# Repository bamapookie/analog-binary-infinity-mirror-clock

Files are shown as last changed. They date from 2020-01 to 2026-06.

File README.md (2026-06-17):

# Analog Binary Infinity Mirror Clock

Plans, parts, and code for building your very own clock that no one can read. (Except you... maybe.)

> **Status:** Resurrecting an abandoned build. The firmware targets an Adafruit
> ItsyBitsy M4 (SAMD51) driving six APA102/DotStar rings, disciplined by a GPS
> module so it never needs to be set. See [`ROADMAP.md`](ROADMAP.md) for what's
> planned next (library extraction, a desk-sized revision, and magnet-based
> configuration). Project boards on [CADLAB.io](https://cadlab.io/project/2407).

## The Concept

Everyone knows analog clocks--2 or 3 hands moving around a clock face, indicating hours, minutes, and sometimes
seconds. It is easy to get a sense of time progressing by watching the hands move around, or gauging the position of one
hand in relation to the numbers (or even just the angles) to fill in an appropriate sense of precision.

Most people have seen binary clocks--Several obscure lights flickering on and off in a seemingly random pattern with
no markings to indicate number groupings, then having to decode the lights into a usable number. Some people cheat and
use Binary Coded Decimal in order to only have to decode one digit at a time.

What the world really needs is a way to combine the obscurity and complexity of decoding a binary number into a usable
format with the intrinsic sense of progress you get from the movement of the hands of an analog clock.

Thus began my quest to build a Binary Analog Clock! 11 hands moving around a clock face with only a '0' and a '1' to
adorn it. Now how the #^%\$% am I going to build a clock with 11 hands? I searched Google. Couldn't find anything
remotely resembling a kit for building an 11 handed clock. (IKR?) So I sat on it for a while, then I saw an infinity
mirror with NeoPixels in it, and it clicked. The infinity mirror effect could look like a line, and radiating in from
pixels on the outer ring, it could look like a hand. I finally had my plan. I dropped a boatload of money on Adafruit
and my local MicroCenter (See the materials list below, and thanks LadyAda for having such a fantastic operation.) and
started to work.

## The Plan

#### Basic plan

Basically, an infinity mirror is made with two mirrors facing each other. The mirror closest to you is semi-transparent.
This allows some of the light through, but the rest of the light bounces back and repeats the process. This makes the
space between the mirrors appear to extend beyond the back mirror. Between the mirrors, we will place 6 concentric
circles of DotStar pixels facing inward. Each of these will be a "hand" representing one bit of the binary number.
All six rings will be used to indicate minutes (2^6 = 64 > 60). The five innermost circles will also indicate hours
(2^5 = 32 > 24), using a slightly wider hand to distinguish it from the minute hands. I also have a plan for indicating
seconds by having the seconds "ripple" out from the corresponding minute hands, making the clock even more unreadable.

#### Intermediate plan

We want the "mechanics" to be small, so we'll use an Itsy Bitsy M4 to drive everything with a few other chips to bring up
the logic voltage to the DotStars. We'll print PCBs to mount it all on and stick it behind the clock.

#### Complex Plan

This is a clock. Clocks, in their default state, only blink 001100:000000 over and over again. We don't want that! We
want a clock that keeps its time. Moreover, we don't want to have to set it. Ever. Let's throw a GPS on there and we
won't ever have to set it! We'll just need to spend and extra few weeks figuring out the GPS code, how to set the time
from it, and wait... GPS time isn't the same as UTC time? UTC time has leap seconds? The standard time library
doesn't handle leap seconds or milliseconds? This won't do.

#### Overly Complex Plan

Let's rewrite the Arduino Time libraries, the GPS libraries, and the TimeZone libraries to handle leap seconds and
milliseconds. And because I laugh at my own jokes, we'll make it blink 001100:000000 for a little while when we turn
it on.

Okay. Maybe that is overdoing it. How about we keep track of the seconds separately, and just use the time libraries
for minute-level precision. We will increment the seconds using the PPS signal and data from the GPS on when leap
seconds occur, then update the GPS time when we determine a minute rollover has occured. This will also handle the
delay between the actual start of a second and the time that the NMEA message containing the time arrives from the GPS.

## The Implementation

Parts acquired... let's go!

While the final product will use an Itsy Bitsy M4 Express, I'm prototyping it with a Feather M4 Express. When I get the
IBM4, I'll use the Feather M4 Express along with an OLED display and another chip to measure the power usage of the
DotStars to make sure I have the right size power supply.

So now I have the breadboard out with one freshly soldered Feather M4 Express, one freshly soldered GPS Breakout board,
and a 1 meter length DotStar Strip.

#### Phase 1 - Testing the components

Using the default strandtest.ino from Adafruit with minor modifications, I tested out the DotStar strips. (See the
[`examples/`](examples/) folder for the strand and GPS bring-up sketches.)

PPS Test

GPS Test

#### Phase 2 - Hardware

Designing the PCB
Designing the Frame

#### Phase 3 - Writing the code

## Useful Links

##### Parts Lists

- https://www.adafruit.com/wishlists?wid=482342

##### Microcontrollers

- https://learn.adafruit.com/adafruit-feather-m4-express-atsamd51/overview
- https://learn.adafruit.com/introducing-adafruit-itsybitsy-m4/overview

##### Programming (C, C++)

- https://www.arduino.cc/reference/en/#functions
- http://www.gammon.com.au/forum/?id=11488
- https://forum.arduino.cc/index.php?topic=503368.0
- https://create.arduino.cc/projecthub/GadgetsToGrow/don-t-delay-use-an-arduino-task-scheduler-today-215cfe
- https://github.com/arkhipenko/TaskScheduler

##### DotStars

- https://learn.adafruit.com/adafruit-dotstar-leds/overview
- https://github.com/adafruit/Adafruit_DotStar
- https://wp.josh.com/2015/12/22/getting-real-using-blind-send-spi-to-turbocharge-the-adafruit-dotstar-library/

##### FastLED

- https://fastled.io/
- https://github.com/FastLED/FastLED
- https://www.reddit.com/r/FastLED/

##### GPS

- http://www.hhhh.org/wiml/proj/nmeaxor.html
- http://aprs.gids.nl/nmea/
- http://arduiniana.org/libraries/tinygpsplus/
- https://github.com/mikalhart/TinyGPSPlus
- http://www.flytron.com/pdf/MTK_commands.pdf
- https://en.wikipedia.org/wiki/NMEA_0183

###### Adafruit Ultimate GPS Breakout Board

- https://github.com/adafruit/Adafruit_GPS
- https://learn.adafruit.com/adafruit-ultimate-gps/overview
- https://forums.adafruit.com/viewtopic.php?f=19&t=148591&p=734292#p733660
- https://cdn-shop.adafruit.com/datasheets/GlobalTop-FGPMMOPA6C-Datasheet-V0A-Preliminary.pdf
- https://cdn-shop.adafruit.com/datasheets/PMTK_A11.pdf
- http://www.alphamicrowireless.com/franchises/globaltop-technology/pa6h.aspx

###### SparkFun GPS Breakout - XA1110

- https://www.sparkfun.com/products/14414
- https://www.sparkfun.com/datasheets/GPS/Modules/PMTK_Protocol.pdf

##### Components
- https://learn.sparkfun.com/tutorials/capacitors/all

##### Time

- https://www.pjrc.com/teensy/td_libs_Time.html
- https://www.davidpilling.com/wiki/index.php/GPS#a6
- https://github.com/PaulStoffregen/Time
- https://forum.arduino.cc/index.php?topic=503368.0
- https://github.com/JChristensen/Timezone

##### PCBs

- https://www.autodesk.com/products/eagle/free-download
- https://learn.adafruit.com/making-pcbs-with-oshpark-and-eagle/ordering-and-assembly
- https://oshpark.com/
- http://kicad-pcb.org/download/windows/
- https://cadlab.io ([My project](https://cadlab.io/project/2407)). 

##### Soldering

- https://www.youtube.com/watch?v=VxMV6wGS3NY

##### Random

- https://arduino.stackexchange.com/questions/348/how-to-organize-my-arduino-projects-structure-for-easy-source-control
- http://www.gammon.com.au/forum/?id=11488

## Addendum
#### Leap Seconds
During testing of the GPS is when I discovered the possible occurrence of leap seconds.  Every couple of years, or so, 
an extra second (or 2) is added to (or removed from) the last minute of June or December, UTC.  So instead of the 
seconds counting 58, 59, 60/0, 1, 2, etc., they might add an extra second (59, 60, 61/0, 1, 2), an extra 2 seconds 
(59, 60, 61, 62/0, 1, 2), or take away a second (58, 59/0, 1, 2).  All of this is to keep UTC in sync with UT1, which is 
the actual time based on the position of the earth in relation to the position of the stars.   UT1 drifts due to tidal 
forces changing the speed that the earth rotates.  Whenever the difference between UTC and UT1 reaches .9 seconds, leap 
seconds are used to correct the imbalance.

Unix clocks usually just ignore this.  They just leave the time at 23:59:59 until 00:00:00 eventually gets here.  All of
the time libraries used in Arduino environments also ignore this, and make no attempt to handle it.

## Repository Layout

- `src/` — the clock firmware (`main.cpp`).
- `lib/` — project libraries: board pin maps (`abimc_pcb`) and GPS command sets (`xa1110`, `mtk33x9`).
- `examples/` — standalone bring-up sketches for the LEDs and GPS (see [`examples/README.md`](examples/README.md)).
- `test/` — reserved for PlatformIO unit tests.
- `pcb/` — Autodesk EAGLE schematic and board files.
- `images/` — clock-face artwork (SVG/XCF).

## Building

This is a [PlatformIO](https://platformio.org/) project. With the PlatformIO CLI installed:

```sh
pio run                 # build the firmware
pio run --target upload # flash a connected ItsyBitsy M4
pio device monitor      # open the serial monitor
```

## License

Dual-licensed: firmware under the MIT License, hardware (PCB and artwork) under
CERN-OHL-S v2. See [`LICENSE.md`](LICENSE.md) for details.

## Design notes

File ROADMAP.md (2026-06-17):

# Roadmap

This project is being resurrected. This document tracks the plan so the context
isn't lost again. Items are grouped into tracks; tracks can progress in parallel.

## Guiding principles

- **GPS-first, offline-first.** A big part of the appeal is that the clock needs
  no Wi-Fi and never needs to be set. It should work anywhere on Earth out of the
  box. Network time (NTP) may be added later as an *optional* convenience, never a
  requirement.
- **Losing power or signal is a feature.** With no valid time data, the clock
  should flash `12:00` like an old VCR until it reacquires a fix. (The firmware
  already approximates this in `set12oClock()`; finishing/polishing this is a
  firmware task.)
- **Unreadable on purpose.** The whole point is a clock that is hard to read but
  still gives an analog sense of time passing.
- **Outsource fabrication, minimize hand-assembly.** The maintainer is strong on
  software but not on hands-on building, so prefer designs that can be
  manufactured and assembled by a service (PCB assembly / printed enclosures)
  rather than hand-soldered or hand-fitted — as long as it stays reasonably
  inexpensive at hobby quantities. Concretely: favor turnkey **PCBA** (board +
  parts placed and reflowed by the fab), off-the-shelf modules over discrete
  bring-up, connectors/sockets over soldered-in wiring, and enclosure processes
  available from print/CNC service bureaus over methods needing a home shop. The
  CERN-OHL-S license already permits third parties (including fab houses) to make
  the hardware, so this is purely a design-choice principle. Avoid low-volume
  injection molding and anything that only pencils out at industrial quantities.

## Track A — Repository & firmware hygiene (in progress)

- [x] Remove EAGLE autosave/backup cruft and IDE files from version control.
- [x] Fix the non-compiling `adafruit_strand_test` sketch and the duplicated
      block in `fastled_strand_test`.
- [x] Move dev sketches out of `test/` (reserved for unit tests) into `examples/`.
- [x] Add dual licensing (MIT firmware + CERN-OHL-S hardware).
- [x] Add continuous integration that builds the firmware with PlatformIO.
- [ ] Pin `lib_deps` versions for reproducible builds.
- [ ] **Produce manufacturing outputs for the existing board** so it can be sent
      to a PCBA service without a home shop: export Gerbers + drill, an
      assembly-house BOM, and a centroid/pick-and-place (CPL) file from the EAGLE
      design, and check them into `pcb/`. (Needs EAGLE/CAD tooling; first step
      toward the outsource-fabrication principle.)
- [ ] **Firmware correctness pass** (from the resurrection audit):
  - [x] Mark ISR-shared globals `volatile` (`ppsStartOfSecondMillis`,
        `ppsStartOfMinuteMillis`, `currentMinute`, `nextLeapMinute`,
        `numberOfLeapSeconds`).
  - [x] Fix the "torn read" guard in `setClock()` (replaced the self-comparison
        with a `noInterrupts()` snapshot of the minute/start-of-minute pair).
  - [x] Bound the array writes in `updateStrandSeconds()` (now wraps with `MOD`)
        so the seconds feature is safe to re-enable.
  - [ ] Actually populate `numberOfLeapSeconds` / `nextLeapMinute` from the parsed
        GPS leap-second fields, or remove the dead parsing — today the leap-second
        feature is wired up but never fed any data.
  - [ ] Finish or remove the commented-out seconds "ripple" rendering.
  - [x] Polish the VCR `12:00` flash for the no-signal state — reviewed; the loop
        already blinks `set12oClock()` at ~1 Hz while GPS time is invalid, which is
        the intended VCR behavior. No change needed beyond confirming it.

## Track B — Library extraction (next)

Break the monolithic `main.cpp` into reusable, host-testable libraries. The key
win is making the time and rendering logic framework-agnostic so it can be unit
tested on a PC via `pio test`, turning `test/` into real tests.

A `native` PlatformIO env plus a `test/test_render/` suite now exist, and CI runs
`pio test -e native` on every push, so the host-test pipeline is live.

- `AbimcTimekeeper` — leap-second-aware, sub-second UTC clock with pluggable time
  *sources* (PPS-disciplined GPS today; NTP/RTC later) behind one interface.
- `abimc_render` — pure, FastLED-free rendering math. **Started:** the hand
  geometry (`computeHand`: positions + sub-pixel leading/trailing fade + ring
  wrap) is extracted from `updateStrand()` and unit tested on the host; the
  firmware now calls it and only applies colour. **Still to move in:** the
  per-ring binary-bit selection, the seconds "ripple", and the planned motion
  rules (capped-speed slewing, 60-on-64 catch-up, leap-second pacing).
- `AbimcConfig` — settings model (seconds on/off, timezone, custom-tz rules) plus
  persistence. Back-end for the magnet UI below.
- `abimc_pcb` — already a library; keep, versioned per board revision.

### Renderer motion & display rules (planned)

Concrete behaviors `AbimcRender` (and the no-signal display) must implement:

- **Hands never jump.** Define a `MAX_HAND_SPEED` (always greater than the
  fastest *normal* speed of the 1-minute hand) and, whenever a hand's target
  position differs from where it is now, advance it toward the target at that
  capped speed instead of snapping. This smooths out time corrections and the
  catch-up below.
- **60 minutes on a 64-"minute" ring.** The rings run on power-of-two periods
  (…32, 64), so a 64-period ring only travels 60/64 of the way around in a real
  hour and would sit ~4 minutes short of the top at the turn of the hour, when
  all hands should point straight up. After such a hand passes the bottom of its
  ring, speed it up slightly so it reaches the top exactly as the minutes roll
  over to `:00`. (Verify whether the current `ST()`/period math already does
  this — believed not yet implemented.) The same catch-up applies one level down
  to the **seconds within a minute**: 60 seconds mapped onto a power-of-two
  period second hand must likewise speed up after the bottom so it reaches the
  top exactly as the second hand completes the minute.
- **Leap-second pacing.** Conversely, during a minute that contains a leap second
  the hands should move one second slower (or faster, for a removed second) so a
  61- (or 59-) second minute still lands the hands correctly at the rollover.
  This ties into wiring up `numberOfLeapSeconds` / `nextLeapMinute`.
- **Timezone-aware no-signal flash.** The "no time acquired yet" flash is
  normally `12:00` (VCR style), but it should depend on the active timezone /
  custom profile: when the **Margaritaville** timezone is in effect, flash `17`
  ("it's 5 o'clock somewhere") instead of `12`.

## Track C — Hardware v2 (deferred; no hardware change yet)

Captured for when we're ready. Current decision is to **keep the existing
ItsyBitsy M4 hardware** and do the software work first. Design this revision for
**turnkey manufacturing** per the outsourcing principle: one assembled PCB from a
PCBA service rather than a dev board plus hand-wiring.

- **MCU candidates if/when we revise:** ESP32-S3 (Wi-Fi/BLE, NTP, OTA, BLE config)
  or RP2350/Pico 2 W (PIO-driven LEDs, deterministic timing). Either would keep
  GPS as the primary, offline time source per the guiding principles. **Prefer a
  bare module the fab can place** (e.g. ESP32-S3-WROOM, RP2350 + flash) so there
  is no separate dev board to hand-solder; pick parts from the assembler's
  standard library (e.g. JLCPCB basic/extended) to keep PCBA cheap.
- **LEDs:** stay with APA102-class (separate clock line = high PWM refresh and
  global brightness, which makes smooth moving hands look good). Move to the
  smaller APA102-2020 / SK9822 package to enable the desk-size shrink; custom
  flex-PCB rings at small diameters — and have the **LEDs placed by the fab**
  (hand-placing hundreds of 2020 parts is exactly what we're trying to avoid).
- **GPS:** upgrade the 6-year-old MTK3339/XA1110 to a u-blox MAX-M10S — better
  sensitivity, lower power, still has PPS, and reports current + pending leap
  seconds directly (UBX-NAV-TIMELS), which would greatly simplify the leap-second
  code. A drop-in **castellated GPS module** the assembler can reflow is ideal.
- **RTC:** add a battery-backed DS3231 so time survives power loss without
  reacquiring a fix. Use a battery **holder/socket**, not a soldered-in cell.
- **Power:** budget carefully — 504 APA102 at full white is a theoretical ~30 A;
  rely on brightness limiting and the sparse hands-only display. Use a standard
  barrel-jack/USB-C input module so power is plug-in, not wired.
- **Assembly aim:** the only manual steps should be plugging the ring PCBs into
  the main board via connectors and closing the enclosure — no soldering.

## Track D — Desk-sized enclosure (future)

The original clock was too big. Shrink it to a desk-sized unit, using enclosure
processes available from **online print/CNC service bureaus** (FDM/SLA 3D
printing, laser-cut acrylic) rather than anything needing a home workshop.

- Recompute ring radii for a ~100-150 mm diameter target.
- Smaller infinity-mirror stack and a 3D-printed housing — order prints from a
  service (e.g. JLCPCB/PCBWay 3D printing, Craftcloud, SendCutSend for acrylic)
  and design for that process (tolerances, no support-heavy geometry, snap-fits
  or screw bosses instead of glue where possible).
- Let this constrain the Track B/C PCB so the electronics are designed for
  desk-scale ring counts up front, even if the first v2 build is larger.
- Keep the parts count low and the assembly tool-free so a non-handy builder can
  finish it from manufactured parts.

## Track E — Magnet-based configuration (future)

Configure the clock by dropping small magnets into recesses molded into the 3D
printed back panel. Magnets are non-volatile with no battery, so configuration
survives power loss inherently. The recesses are printed into the housing (a
service print), and the Hall sensors are placed by the PCBA, so this needs no
hand-assembly.

- **Sensing:** digital Hall-effect sensors (e.g., DRV5032), one per recess; use
  *omnipolar* parts so magnet orientation doesn't matter. Route many sensors
  through an I2C I/O expander (MCP23017) or analog mux to save GPIO.
- **Dial option:** a single 3D Hall sensor (TLV493D / MLX90393) under a rotatable
  magnet senses angle — e.g., rotate to dial in a UTC offset.
- **Proposed config bits:**
  - 1 recess = seconds hand on/off.
  - 1 recess = DST on/off.
  - A small group of recesses (binary) or a Hall dial = timezone / UTC offset.
  - 1 recess = "use custom profile", loading a personal timezone
    (e.g. `North_America/Margaritaville`) defined once over BLE/serial and saved.

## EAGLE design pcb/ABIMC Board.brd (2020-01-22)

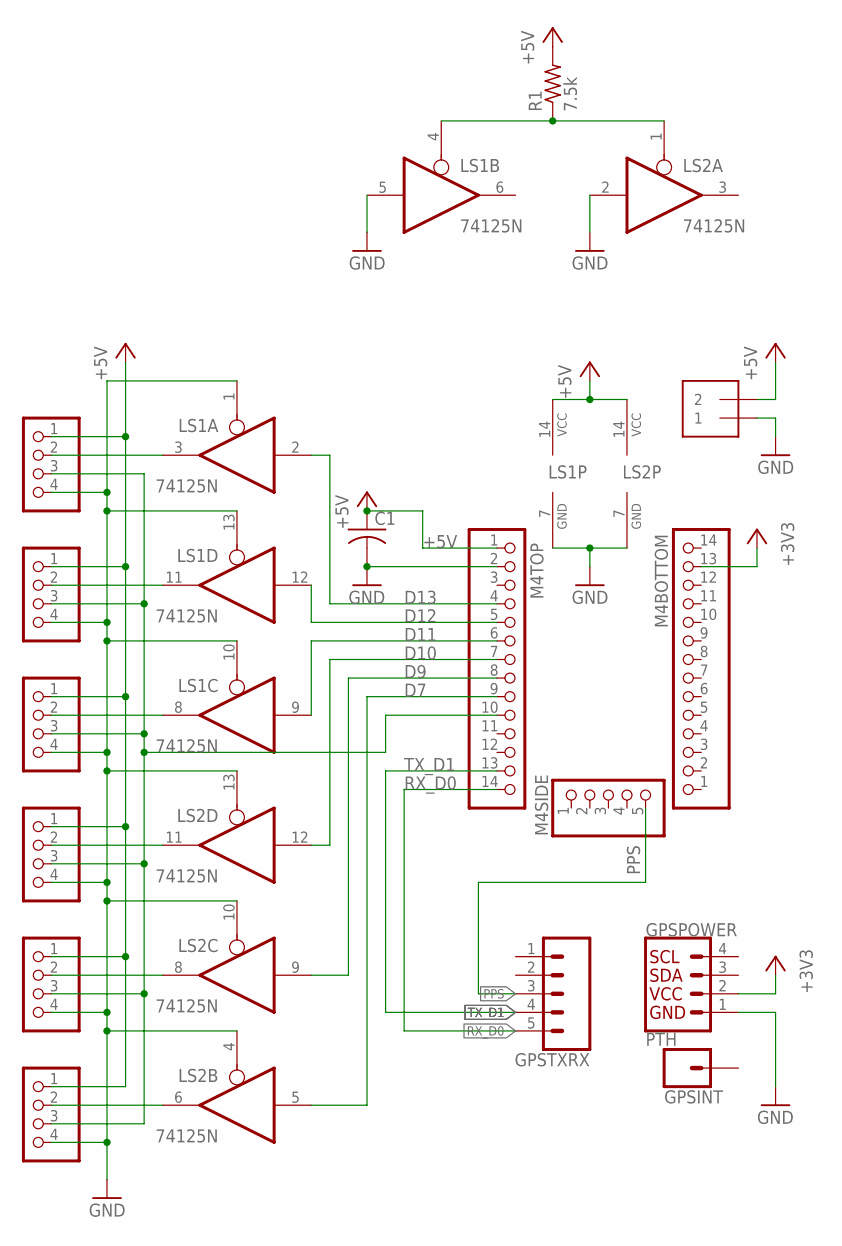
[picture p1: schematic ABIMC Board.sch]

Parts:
C1: C-US050-024X044; C050-024X044
GPSINT: CONN_01PTH_NO_SILK_YES_STOP; 1X01_NO_SILK
GPSPOWER: PTH; 1X04_NO_SILK
GPSTXRX: CONN_05NO_SILK; 1X05_NO_SILK
JP1, JP2, JP3, JP4, JP5, JP6: PINHD-1X4/90; 1X04/90
LS1, LS2: 74125N; DIL14
M4BOTTOM, M4TOP: HEADER-1X14; 1X14_ROUND70
M4SIDE: HEADER-1X570MIL; 1X05_ROUND_70
POWER: 1X2-3.5MM
R1: 7.5k; 0204/7

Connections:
+3V3: GPSPOWER.2 (VCC), M4BOTTOM.13
+5V: C1.1, JP1.1, JP2.1, JP3.1, JP4.1, JP5.1, JP6.1, LS1.14 (VCC), LS2.14 (VCC), M4TOP.1, POWER.2, R1.2
D7: LS2.5 (I), M4TOP.9
D9: LS2.9 (I), M4TOP.8
D10: LS2.12 (I), M4TOP.7
D11: LS1.9 (I), M4TOP.6
D12: LS1.12 (I), M4TOP.5
D13: LS1.2 (I), M4TOP.4
DSDATA: JP1.3, JP2.3, JP3.3, JP4.3, JP5.3, JP6.3, M4TOP.10
GND: C1.2, GPSPOWER.1 (GND), JP1.4, JP2.4, JP3.4, JP4.4, JP5.4, JP6.4, LS1.1 (OE), LS1.5 (I), LS1.7 (GND), LS1.10 (OE), LS1.13 (OE), LS2.2 (I), LS2.4 (OE), LS2.7 (GND), LS2.10 (OE), LS2.13 (OE), M4TOP.2, POWER.1
unnamed: JP1.2, LS1.3 (O)
unnamed: JP2.2, LS1.11 (O)
unnamed: JP4.2, LS2.11 (O)
unnamed: JP5.2, LS2.8 (O)
unnamed: JP6.2, LS2.6 (O)
unnamed: JP3.2, LS1.8 (O)
PPS: GPSTXRX.3, M4SIDE.5
RX_D0: GPSTXRX.5, M4TOP.14
TX_D1: GPSTXRX.4, M4TOP.13
VHI: LS1.4 (OE), LS2.1 (OE), R1.1

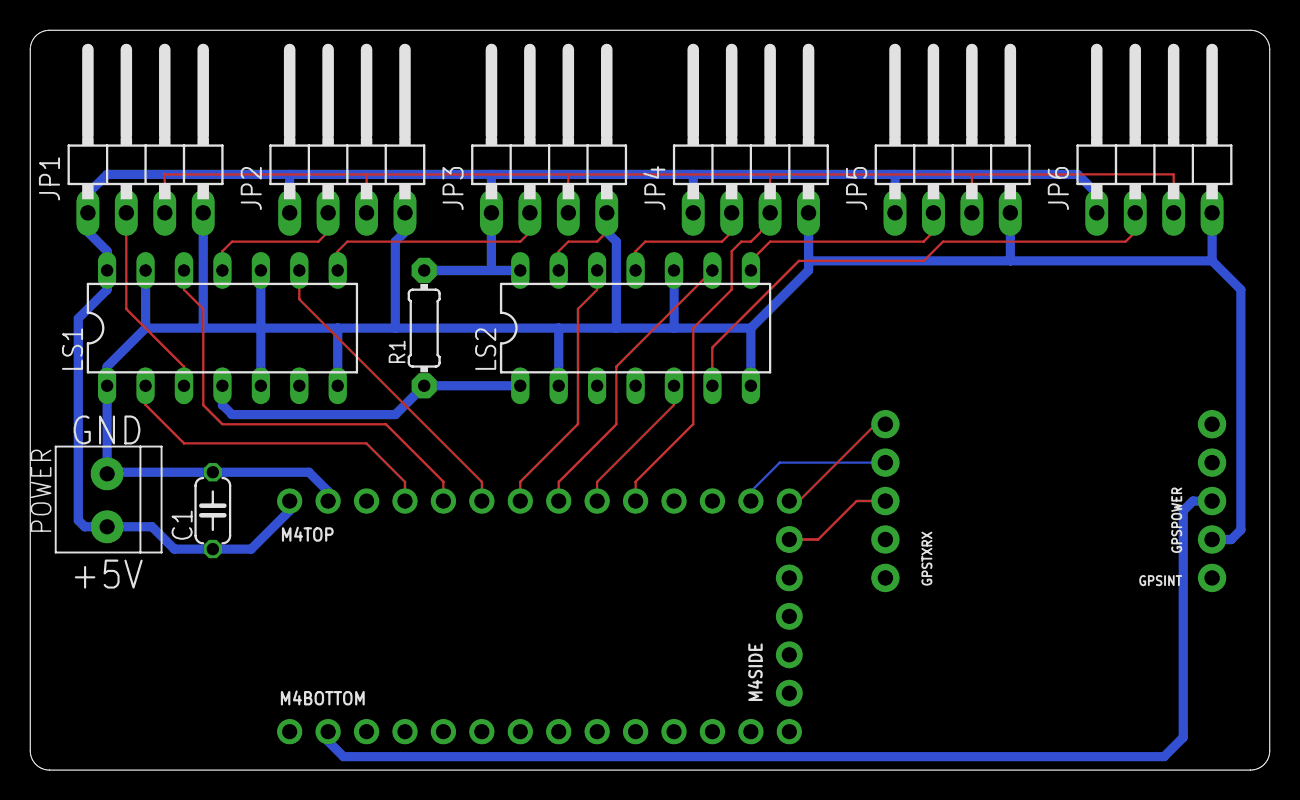
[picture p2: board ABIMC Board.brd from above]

Board: 2 copper layers, 81.9 x 48.9 mm, 17 parts (0 on the bottom side), 20 nets.

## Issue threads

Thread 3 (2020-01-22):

Complete power cycle loses connection to GPS.  Reset fixes.

bamapookie, 2020-01-22:

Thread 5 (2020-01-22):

Cycle colors

bamapookie, 2020-01-22:
Currently, the hour hands are fixed at red, the minute hands are fixed at blue, and the seconds are fixed at Green.  They should cycle through the spectrum, while maintaining separation from the other hands for visibility.

Closed 2020-01-27.

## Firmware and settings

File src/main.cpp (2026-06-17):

#include <Arduino.h>
#include <FastLED.h>
#include <SPI.h>
#include <TimeLib.h>
#include <Timezone.h>
#include <TinyGPS++.h>

#define ABIMC_V_1_3

#include <abimc_pcb.h>
#include <abimc_render.h>
#include <xa1110.h>

#define DEBUG
//
// Settings
// LED Settings
#define STRAND_1_PIXELS 144
#define STRAND_1_OFFSET 0
#define STRAND_1_MINUTES_PERIOD 2
#define STRAND_1_HOURS_PERIOD 2
#define STRAND_2_PIXELS 120
#define STRAND_2_OFFSET 0
#define STRAND_2_MINUTES_PERIOD 4
#define STRAND_2_HOURS_PERIOD 4
#define STRAND_3_PIXELS 96
#define STRAND_3_OFFSET 0
#define STRAND_3_MINUTES_PERIOD 8
#define STRAND_3_HOURS_PERIOD 8
#define STRAND_4_PIXELS 72
#define STRAND_4_OFFSET 0
#define STRAND_4_MINUTES_PERIOD 16
#define STRAND_4_HOURS_PERIOD 16
#define STRAND_5_PIXELS 48
#define STRAND_5_OFFSET 0
#define STRAND_5_MINUTES_PERIOD 32
#define STRAND_5_HOURS_PERIOD 32
#define STRAND_6_PIXELS 24
#define STRAND_6_OFFSET 0
#define STRAND_6_MINUTES_PERIOD 64
#define STRAND_6_HOURS_PERIOD 0

#define FRACTIONAL_BRIGHTNESS 256
#define SECOND_HAND_WIDTH 11
#define SECOND_HAND_PULSE_DURATION_MILLIS 500
#define MINUTE_HAND_WIDTH 1
#define HOUR_HAND_WIDTH 3
#define REFRESH_RATE_HZ 50
#define SPECTRUM_CYCLE_PERIOD_SECONDS 8
#define REFRESH_INTERVAL_MILLIS (1000 / REFRESH_RATE_HZ)

// GPS Settings
#define GPS_FIX_RATE PMTK_API_SET_FIX_CTL_100_MILLIHERTZ
#define GPS_OUTPUT_RATE PMTK_SET_NMEA_UPDATE_100_MILLIHERTZ
#define GPS_OUTPUT PMTK_SET_NMEA_OUTPUT_ZDA
#define GPS_SERIAL_BAUD_RATE 115200
#define GPS_SERIAL_BAUD_RATE_SENTENCE PMTK_SET_BAUD_115200

// Computed values from settings
// Offsets from the computed time.  Used to align the center of the hand with the center of the pixel.
//
#define SECOND_HAND_OFFSET (((1 - (SECOND_HAND_WIDTH)) * (FRACTIONAL_BRIGHTNESS - 1)) / 2)
#define MINUTE_HAND_OFFSET (((1 - (MINUTE_HAND_WIDTH)) * (FRACTIONAL_BRIGHTNESS - 1)) / 2)
#define HOUR_HAND_OFFSET (((1 - (HOUR_HAND_WIDTH)) * (FRACTIONAL_BRIGHTNESS - 1)) / 2)

#define STRAND_1_SECOND_HAND_OFFSET ((SECOND_HAND_OFFSET) + (STRAND_1_OFFSET))
#define STRAND_1_MINUTE_HAND_OFFSET ((MINUTE_HAND_OFFSET) + (STRAND_1_OFFSET))
#define STRAND_1_HOUR_HAND_OFFSET ((HOUR_HAND_OFFSET) + (STRAND_1_OFFSET))
#define STRAND_2_SECOND_HAND_OFFSET ((SECOND_HAND_OFFSET) + (STRAND_2_OFFSET))
#define STRAND_2_MINUTE_HAND_OFFSET ((MINUTE_HAND_OFFSET) + (STRAND_2_OFFSET))
#define STRAND_2_HOUR_HAND_OFFSET ((HOUR_HAND_OFFSET) + (STRAND_2_OFFSET))
#define STRAND_3_SECOND_HAND_OFFSET ((SECOND_HAND_OFFSET) + (STRAND_3_OFFSET))
#define STRAND_3_MINUTE_HAND_OFFSET ((MINUTE_HAND_OFFSET) + (STRAND_3_OFFSET))
#define STRAND_3_HOUR_HAND_OFFSET ((HOUR_HAND_OFFSET) + (STRAND_3_OFFSET))
#define STRAND_4_SECOND_HAND_OFFSET ((SECOND_HAND_OFFSET) + (STRAND_4_OFFSET))
#define STRAND_4_MINUTE_HAND_OFFSET ((MINUTE_HAND_OFFSET) + (STRAND_4_OFFSET))
#define STRAND_4_HOUR_HAND_OFFSET ((HOUR_HAND_OFFSET) + (STRAND_4_OFFSET))
#define STRAND_5_SECOND_HAND_OFFSET ((SECOND_HAND_OFFSET) + (STRAND_5_OFFSET))
#define STRAND_5_MINUTE_HAND_OFFSET ((MINUTE_HAND_OFFSET) + (STRAND_5_OFFSET))
#define STRAND_5_HOUR_HAND_OFFSET ((HOUR_HAND_OFFSET) + (STRAND_5_OFFSET))
#define STRAND_6_SECOND_HAND_OFFSET ((SECOND_HAND_OFFSET) + (STRAND_6_OFFSET))
#define STRAND_6_MINUTE_HAND_OFFSET ((MINUTE_HAND_OFFSET) + (STRAND_6_OFFSET))
#define STRAND_6_HOUR_HAND_OFFSET ((HOUR_HAND_OFFSET) + (STRAND_6_OFFSET))

#define MOD(a, b) ((((a) % (b)) + (b)) % (b))
#define ST(offset, period, pixels, milli) (MOD((offset) + (milli) % (period) * (pixels) / (period), (pixels)))

// Application starts here

CRGB strand1[STRAND_1_PIXELS];  // Outermost
CRGB strand2[STRAND_2_PIXELS];
CRGB strand3[STRAND_3_PIXELS];
CRGB strand4[STRAND_4_PIXELS];
CRGB strand5[STRAND_5_PIXELS];
CRGB strand6[STRAND_6_PIXELS];  // Innermost

// Time Stuff
TimeChangeRule EDT = {"EDT", Second, Sun, Mar, 2, -240};
TimeChangeRule EST = {"EST", First, Sun, Nov, 2, -300};
Timezone myTZ(EDT, EST);

// GPS Stuff
TinyGPSPlus gps;

TinyGPSCustom zdaUtc(gps, "GNZDA", 1);
TinyGPSCustom zdaDay(gps, "GNZDA", 2);
TinyGPSCustom zdaMonth(gps, "GNZDA", 3);
TinyGPSCustom zdaYear(gps, "GNZDA", 4);

TinyGPSCustom pmtkResponseCode(gps, "PMTK001", 1);
TinyGPSCustom pmtk667ActionFlag(gps, "PMTK001", 2);
TinyGPSCustom pmtk667OldLeapSecondOffset(gps, "GNZDA", 5);
TinyGPSCustom pmtk667CurrentUtcTimeOfWeekSeconds(gps, "GNZDA", 6);
TinyGPSCustom pmtk667CurrentUtcWeekNumber(gps, "GNZDA", 7);
TinyGPSCustom pmtk667LeapSecondUtcWeekNumber(gps, "GNZDA", 8);
TinyGPSCustom pmtk667LeapSecondDayOfWeek(gps, "GNZDA", 9);
TinyGPSCustom pmtk667NewLeapSecondOffset(gps, "GNZDA", 10);

// These are shared between the PPS interrupt (pps()) and the main loop, so they
// must be volatile to stop the compiler from caching stale copies in registers.
// On this 32-bit MCU aligned word accesses are atomic, so individual reads are
// safe; setClock() additionally snapshots the related pair under noInterrupts().
volatile time_t currentMinute = 0;
volatile time_t nextLeapMinute = 0;
volatile int numberOfLeapSeconds = 0;
volatile unsigned long ppsStartOfSecondMillis = 0;  // Used for drift calculation
volatile unsigned long ppsStartOfMinuteMillis = 0;  // Used with currentMinute to get complete millisecond precision
// time, accounting for leap seconds

unsigned long secondsInMinute(time_t minute) {
  return 60 + ((minute % 60) == (nextLeapMinute % 60) ? numberOfLeapSeconds : 0);
}

unsigned long secondsInCurrentHour() {
  return 3600 + ((currentMinute % 3600) == (nextLeapMinute % 3600) ? numberOfLeapSeconds : 0);
}

void pps() {
  ppsStartOfSecondMillis = millis();
  unsigned long currentSecond = (ppsStartOfSecondMillis - ppsStartOfMinuteMillis + 500) / 1000;
  boolean minuteRollover = currentSecond == secondsInMinute(currentMinute);
  if (minuteRollover) {
    ppsStartOfMinuteMillis = ppsStartOfSecondMillis;
    currentMinute = ((currentMinute / 60) + 1) * 60;
  }
}

void updateStrand(CRGB* strand,
                  int width,
                  int offset,
                  int period,
                  int pixels,
                  unsigned long long millis,
                  const CRGB& color) {
  // Geometry (which pixels, and the sub-pixel fading of the leading/trailing
  // edges) lives in the host-tested abimc_render library; here we just apply the
  // colour with FastLED. Behaviour matches the original inline math.
  abimc::HandContribution contributions[abimc::MAX_HAND_WIDTH + 1];
  int count = abimc::computeHand(width, offset, period, pixels, millis, contributions);
  for (int i = 0; i < count; i++) {
    CRGB faded = color;
    faded.fadeToBlackBy(contributions[i].fadeBy);
    strand[contributions[i].index] += faded;
  }
}

void updateStrandSeconds(CRGB* strand,
                         time_t displayTime,
                         unsigned long millisSinceStartOfMinute,
                         unsigned long millisSinceStartOfSecond,
                         unsigned long millisSinceStartOfHour,
                         int offset,
                         int period,
                         int pixels,
                         const CHSV& color) {
  CHSV secondHandRender[SECOND_HAND_WIDTH + 1];
  for (auto& i : secondHandRender) {
    i = color;
  }
  unsigned long secondHandDiameter = (SECOND_HAND_WIDTH - 1) * FRACTIONAL_BRIGHTNESS * millisSinceStartOfSecond /
                                     (2 * SECOND_HAND_PULSE_DURATION_MILLIS);

  unsigned long lowerIndex = ((SECOND_HAND_WIDTH - 1) * FRACTIONAL_BRIGHTNESS / 2 - secondHandDiameter);
  unsigned long upperIndex = ((SECOND_HAND_WIDTH - 1) * FRACTIONAL_BRIGHTNESS / 2 + secondHandDiameter);
  secondHandRender[lowerIndex / FRACTIONAL_BRIGHTNESS].value +=
      FRACTIONAL_BRIGHTNESS - lowerIndex % FRACTIONAL_BRIGHTNESS;
  secondHandRender[lowerIndex / FRACTIONAL_BRIGHTNESS + 1].value += lowerIndex % FRACTIONAL_BRIGHTNESS;
  secondHandRender[upperIndex / FRACTIONAL_BRIGHTNESS].value +=
      FRACTIONAL_BRIGHTNESS - upperIndex % FRACTIONAL_BRIGHTNESS;
  secondHandRender[upperIndex / FRACTIONAL_BRIGHTNESS + 1].value += upperIndex % FRACTIONAL_BRIGHTNESS;
  if ((millisSinceStartOfMinute / 1000) % 2 > 0) {
    int secondHand = ST(offset, period * secondsInMinute(displayTime) * 1000, pixels, millisSinceStartOfHour);
    for (int i = 0; i < SECOND_HAND_WIDTH + 1; i++) {
      // Wrap around the ring like updateStrand() does; secondHand + i can run
      // past the end of the strand otherwise.
      strand[MOD(secondHand + i, pixels)] += secondHandRender[i];
    }
  }
}

void setClock() {
  // Take a consistent snapshot of the values the PPS interrupt updates. The
  // interrupt writes currentMinute and ppsStartOfMinuteMillis together on a
  // minute rollover, so copy them with interrupts disabled to avoid reading one
  // of them from before the rollover and the other from after. millis() is read
  // inside the same critical section so the "now" reference shares the same time
  // base -- otherwise a rollover in the gap could make millisSinceStartOfMinute
  // exceed 60s for a frame.
  noInterrupts();
  time_t snapshotMinute = currentMinute;
  unsigned long displayStartOfMinuteMillis = ppsStartOfMinuteMillis;
  unsigned long displayMillis = millis();
  interrupts();

  time_t displayTime = myTZ.toLocal(snapshotMinute);

  // Determine hand positions
  unsigned long millisSinceStartOfMinute = displayMillis - displayStartOfMinuteMillis;
  unsigned long millisSinceStartOfSecond = millisSinceStartOfMinute % 1000;
  (void)millisSinceStartOfSecond;  // consumed by the (currently disabled) seconds-hand render below
  unsigned long millisSinceStartOfHour = (displayTime % 3600) * 1000 + millisSinceStartOfMinute;

  // Determine color offset (PERIOD_IN_SECONDS * 1024 milliseconds / 256 colors in range)
  uint8_t hueOffset = (displayMillis / (SPECTRUM_CYCLE_PERIOD_SECONDS * 4)) % 256;

  // Strand 1
  // start point of hand (minute) = 1/2 of brightness - 1/2 of width of hand + (millisSinceStartOfHour % millisInPeriod)
  // / millisPerFractionalPixel

  // Set hours on strands
  unsigned long millisSinceStartOfDay = hour(displayTime) * secondsInCurrentHour() * 1000 + millisSinceStartOfHour;
  // Not accurate if the current day has leap seconds.  Uses secondsInCurrentHour to handle creating an interval that
  // matches the period of the current hour.
  updateStrand(strand1, HOUR_HAND_WIDTH, STRAND_1_HOUR_HAND_OFFSET,
               STRAND_1_HOURS_PERIOD * secondsInCurrentHour() * 1000, STRAND_1_PIXELS, millisSinceStartOfDay,
               CHSV(hueOffset, 255, 255));
  updateStrand(strand2, HOUR_HAND_WIDTH, STRAND_2_HOUR_HAND_OFFSET,
               STRAND_2_HOURS_PERIOD * secondsInCurrentHour() * 1000, STRAND_2_PIXELS, millisSinceStartOfDay,
               CHSV(hueOffset + 32, 255, 255));
  updateStrand(strand3, HOUR_HAND_WIDTH, STRAND_3_HOUR_HAND_OFFSET,
               STRAND_3_HOURS_PERIOD * secondsInCurrentHour() * 1000, STRAND_3_PIXELS, millisSinceStartOfDay,
               CHSV(hueOffset + 64, 255, 255));
  updateStrand(strand4, HOUR_HAND_WIDTH, STRAND_4_HOUR_HAND_OFFSET,
               STRAND_4_HOURS_PERIOD * secondsInCurrentHour() * 1000, STRAND_4_PIXELS, millisSinceStartOfDay,
               CHSV(hueOffset + 96, 255, 255));
  updateStrand(strand5, HOUR_HAND_WIDTH, STRAND_5_HOUR_HAND_OFFSET,
               STRAND_5_HOURS_PERIOD * secondsInCurrentHour() * 1000, STRAND_5_PIXELS, millisSinceStartOfDay,
               CHSV(hueOffset + 128, 255, 255));
  updateStrand(strand6, HOUR_HAND_WIDTH, STRAND_6_HOUR_HAND_OFFSET,
               STRAND_6_HOURS_PERIOD * secondsInCurrentHour() * 1000, STRAND_6_PIXELS, millisSinceStartOfDay,
               CHSV(hueOffset + 160, 255, 255));

  // Set minutes on strands
  updateStrand(strand1, MINUTE_HAND_WIDTH, STRAND_1_MINUTE_HAND_OFFSET,
               STRAND_1_MINUTES_PERIOD * secondsInMinute(displayTime) * 1000, STRAND_1_PIXELS, millisSinceStartOfHour,
               CHSV(hueOffset + 160, 255, 255));
  updateStrand(strand2, MINUTE_HAND_WIDTH, STRAND_2_MINUTE_HAND_OFFSET,
               STRAND_2_MINUTES_PERIOD * secondsInMinute(displayTime) * 1000, STRAND_2_PIXELS, millisSinceStartOfHour,
               CHSV(hueOffset + 192, 255, 255));
  updateStrand(strand3, MINUTE_HAND_WIDTH, STRAND_3_MINUTE_HAND_OFFSET,
               STRAND_3_MINUTES_PERIOD * secondsInMinute(displayTime) * 1000, STRAND_3_PIXELS, millisSinceStartOfHour,
               CHSV(hueOffset + 224, 255, 255));
  updateStrand(strand4, MINUTE_HAND_WIDTH, STRAND_4_MINUTE_HAND_OFFSET,
               STRAND_4_MINUTES_PERIOD * secondsInMinute(displayTime) * 1000, STRAND_4_PIXELS, millisSinceStartOfHour,
               CHSV(hueOffset, 255, 255));
  updateStrand(strand5, MINUTE_HAND_WIDTH, STRAND_5_MINUTE_HAND_OFFSET,
               STRAND_5_MINUTES_PERIOD * secondsInMinute(displayTime) * 1000, STRAND_5_PIXELS, millisSinceStartOfHour,
               CHSV(hueOffset + 32, 255, 255));
  updateStrand(strand6, MINUTE_HAND_WIDTH, STRAND_6_MINUTE_HAND_OFFSET,
               STRAND_6_MINUTES_PERIOD * secondsInMinute(displayTime) * 1000, STRAND_6_PIXELS, millisSinceStartOfHour,
               CHSV(hueOffset + 64, 255, 255));

  //   // Set seconds on strands
  //   if (millisSinceStartOfSecond < SECOND_HAND_PULSE_DURATION_MILLIS) {
  //     updateStrandSeconds(strand1, displayTime, millisSinceStartOfMinute, millisSinceStartOfSecond,
  //                         millisSinceStartOfHour, STRAND_1_SECOND_HAND_OFFSET, STRAND_1_MINUTES_PERIOD,
  //                         STRAND_1_FRACTIONAL_PIXELS, CHSV(hueOffset + 96, 255, 255));
  //     updateStrandSeconds(strand2, displayTime, millisSinceStartOfMinute, millisSinceStartOfSecond,
  //                         millisSinceStartOfHour, STRAND_2_SECOND_HAND_OFFSET, STRAND_2_MINUTES_PERIOD,
  //                         STRAND_2_FRACTIONAL_PIXELS, CHSV(hueOffset + 128, 255, 255));
  //     updateStrandSeconds(strand3, displayTime, millisSinceStartOfMinute, millisSinceStartOfSecond,
  //                         millisSinceStartOfHour, STRAND_3_SECOND_HAND_OFFSET, STRAND_3_MINUTES_PERIOD,
  //                         STRAND_3_FRACTIONAL_PIXELS, CHSV(hueOffset + 160, 255, 255));
  //     updateStrandSeconds(strand4, displayTime, millisSinceStartOfMinute, millisSinceStartOfSecond,
  //                         millisSinceStartOfHour, STRAND_4_SECOND_HAND_OFFSET, STRAND_4_MINUTES_PERIOD,
  //                         STRAND_4_FRACTIONAL_PIXELS, CHSV(hueOffset + 192, 255, 255));
  //   }
}

void set12oClock() {
  uint8_t hueOffset = (millis() / (SPECTRUM_CYCLE_PERIOD_SECONDS * 4)) % 256;
  strand1[STRAND_1_PIXELS - 1] = strand1[1] = strand4[0] = CHSV(hueOffset, 255, 255);
  strand2[STRAND_2_PIXELS - 1] = strand2[1] = strand5[0] = CHSV(hueOffset + 32, 255, 255);
  strand3[STRAND_3_PIXELS / 2 - 1] = strand3[STRAND_3_PIXELS / 2] = strand3[STRAND_3_PIXELS / 2 + 1] = strand6[0] =
      CHSV(hueOffset + 64, 255, 255);
  strand4[STRAND_4_PIXELS / 2 - 1] = strand4[STRAND_4_PIXELS / 2] = strand4[STRAND_4_PIXELS / 2 + 1] =
      CHSV(hueOffset + 96, 255, 255);
  strand5[STRAND_5_PIXELS - 1] = strand5[1] = CHSV(hueOffset + 128, 255, 255);
  strand6[STRAND_6_PIXELS - 1] = strand6[1] = strand1[0] = CHSV(hueOffset + 160, 255, 255);
  strand2[0] = CHSV(hueOffset + 192, 255, 255);
  strand3[0] = CHSV(hueOffset + 224, 255, 255);
}

void setup() {
  FastLED.addLeds<APA102, STRAND_1_DATA_PIN, STRAND_1_CLOCK_PIN, BGR>(strand1, STRAND_1_PIXELS);
  FastLED.addLeds<APA102, STRAND_2_DATA_PIN, STRAND_2_CLOCK_PIN, BGR>(strand2, STRAND_2_PIXELS);
  FastLED.addLeds<APA102, STRAND_3_DATA_PIN, STRAND_3_CLOCK_PIN, BGR>(strand3, STRAND_3_PIXELS);
  FastLED.addLeds<APA102, STRAND_4_DATA_PIN, STRAND_4_CLOCK_PIN, BGR>(strand4, STRAND_4_PIXELS);
  FastLED.addLeds<APA102, STRAND_5_DATA_PIN, STRAND_5_CLOCK_PIN, BGR>(strand5, STRAND_5_PIXELS);
  FastLED.addLeds<APA102, STRAND_6_DATA_PIN, STRAND_6_CLOCK_PIN, BGR>(strand6, STRAND_6_PIXELS);
  GPS_SERIAL.begin(GPS_SERIAL_BAUD_RATE);
  GPS_SERIAL.println(GPS_SERIAL_BAUD_RATE_SENTENCE);
  GPS_SERIAL.println(GPS_FIX_RATE);
  GPS_SERIAL.println(GPS_OUTPUT_RATE);
  GPS_SERIAL.println(GPS_OUTPUT);
  GPS_SERIAL.println();
  attachInterrupt(digitalPinToInterrupt(GPS_PPS_PIN), pps, RISING);
#ifdef DEBUG
  Serial.begin(9600);
#endif
}

// Refresh rate timing
unsigned long startTimeMillis;
unsigned long lastRefreshMillis;

#ifdef DEBUG
unsigned long debugRefreshSum = 0;
unsigned long debugRefreshCount = 0;
#endif

void loop() {
  startTimeMillis = millis();
  if (startTimeMillis - lastRefreshMillis > REFRESH_INTERVAL_MILLIS) {
    if (zdaUtc.isValid()) {
      setClock();
    } else if (startTimeMillis % 1024 < 512) {
      set12oClock();
    }

    // Show
    FastLED.show();

    // Clear pixels
    for (auto& i : strand1) {
      i = CRGB::Black;
    }
    for (auto& i : strand2) {
      i = CRGB::Black;
    }
    for (auto& i : strand3) {
      i = CRGB::Black;
    }
    for (auto& i : strand4) {
      i = CRGB::Black;
    }
    for (auto& i : strand5) {
      i = CRGB::Black;
    }
    for (auto& i : strand6) {
      i = CRGB::Black;
    }

    // Set next refresh (startTimeMillis + 16.67 = 60Hz, startTimeMillis + 10 = 100Hz)
    lastRefreshMillis = startTimeMillis;

#ifdef DEBUG
    debugRefreshSum += millis() - startTimeMillis;
    debugRefreshCount++;
#endif
  }
  // Check for GPS updates
  while (GPS_SERIAL.available()) {
    gps.encode(GPS_SERIAL.read());
  }
  if (zdaUtc.isUpdated()) {
    tmElements_t tm;
    tm.Year = CalendarYrToTm(atoi(zdaYear.value()));
    tm.Month = atoi(zdaMonth.value());
    tm.Day = atoi(zdaDay.value());
    char hr[2], min[2], sec[2], ms[3];
    uint8_t seconds;
    uint32_t milliseconds;
    sscanf(zdaUtc.value(), "%2s%2s%2s.%3s", hr, min, sec, ms);
    tm.Hour = atoi(hr);
    tm.Minute = atoi(min);
    seconds = atoi(sec);
    milliseconds = atoi(ms) + zdaUtc.age() + (seconds * 1000);
    tm.Second = 0;

    time_t gpsMinute = makeTime(tm);
    if (gpsMinute != currentMinute) {
      currentMinute = gpsMinute;
      if (seconds != (ppsStartOfSecondMillis - ppsStartOfMinuteMillis + 200) / 1000) {
        ppsStartOfMinuteMillis = ppsStartOfSecondMillis - (seconds * 1000);
      }
    }
#ifdef DEBUG
    Serial.printf("Delay in ms: %d\n", millis() - ppsStartOfMinuteMillis - milliseconds);
    Serial.printf("Display time in ms: %d.%03d\n", (debugRefreshSum * 1000 / debugRefreshCount) / 1000,
                  (debugRefreshSum * 1000 / debugRefreshCount) % 1000);
    debugRefreshSum = 0;
    debugRefreshCount = 0;
#endif
  }
}

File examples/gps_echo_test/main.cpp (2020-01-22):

#include <Arduino.h>
#include <SPI.h>
#include <xa1110.h>

void setup() {
  while (!Serial)
    ;
  while (!Serial1)
    ;
  Serial.begin(9600);
  // fixBaudRate();
  Serial1.begin(115200);
  Serial1.println("$PMTK250,3,3,115200*1E");
  Serial1.println("$PMTK253,0*2A");
  Serial1.println(PMTK_SET_BAUD_115200);
}

void loop() {
  while (Serial.available())
    Serial1.write(Serial.read());
  while (Serial1.available())
    Serial.write(Serial1.read());
}

void fixBaudRate() {
  Serial.println("Setting 4800.");
  Serial1.begin(4800);  // 4800,9600,14400,19200,38400,57600,115200,230400,460800,921600
  Serial1.println("$PMTK250,3,3,115200*1E");
  Serial1.println("$PMTK253,0*2A");
  Serial1.println(PMTK_SET_BAUD_115200);
  delay(500);
  Serial1.end();
  delay(500);
  Serial.println("Setting 9600.");
  Serial1.begin(9600);  // 4800,9600,14400,19200,38400,57600,115200,230400,460800,921600
  Serial1.println("$PMTK250,3,3,115200*1E");
  Serial1.println("$PMTK253,0*2A");
  Serial1.println(PMTK_SET_BAUD_115200);
  delay(500);
  Serial1.end();
  delay(500);
  Serial.println("Setting 14400.");
  Serial1.begin(14400);  // 4800,9600,14400,19200,38400,57600,115200,230400,460800,921600
  Serial1.println("$PMTK250,3,3,115200*1E");
  Serial1.println("$PMTK253,0*2A");
  Serial1.println(PMTK_SET_BAUD_115200);
  delay(500);
  Serial1.end();
  delay(500);
  Serial.println("Setting 19200.");
  Serial1.begin(19200);  // 4800,9600,14400,19200,38400,57600,115200,230400,460800,921600
  Serial1.println("$PMTK250,3,3,115200*1E");
  Serial1.println("$PMTK253,0*2A");
  Serial1.println(PMTK_SET_BAUD_115200);
  delay(500);
  Serial1.end();
  delay(500);
  Serial.println("Setting 38400.");
  Serial1.begin(38400);  // 4800,9600,14400,19200,38400,57600,115200,230400,460800,921600
  Serial1.println("$PMTK250,3,3,115200*1E");
  Serial1.println("$PMTK253,0*2A");
  Serial1.println(PMTK_SET_BAUD_115200);
  delay(500);
  Serial1.end();
  delay(500);
  Serial.println("Setting 57600.");
  Serial1.begin(57600);  // 4800,9600,14400,19200,38400,57600,115200,230400,460800,921600
  Serial1.println("$PMTK250,3,3,115200*1E");
  Serial1.println("$PMTK253,0*2A");
  Serial1.println(PMTK_SET_BAUD_115200);
  delay(500);
  Serial1.end();
  delay(500);
  Serial.println("Setting 115200.");
  Serial1.begin(115200);  // 4800,9600,14400,19200,38400,57600,115200,230400,460800,921600
  Serial1.println("$PMTK250,3,3,115200*1E");
  Serial1.println("$PMTK253,0*2A");
  Serial1.println(PMTK_SET_BAUD_115200);
  delay(500);
  Serial1.end();
  delay(500);
  Serial.println("Setting 230400.");
  Serial1.begin(230400);  // 4800,9600,14400,19200,38400,57600,115200,230400,460800,921600
  Serial1.println("$PMTK250,3,3,115200*1E");
  Serial1.println("$PMTK253,0*2A");
  Serial1.println(PMTK_SET_BAUD_115200);
  delay(500);
  Serial1.end();
  delay(500);
  Serial.println("Setting 460800.");
  Serial1.begin(460800);  // 4800,9600,14400,19200,38400,57600,115200,230400,460800,921600
  Serial1.println("$PMTK250,3,3,115200*1E");
  Serial1.println("$PMTK253,0*2A");
  Serial1.println(PMTK_SET_BAUD_115200);
  delay(500);
  Serial1.end();
  delay(500);
  Serial.println("Setting 921600.");
  Serial1.begin(921600);  // 4800,9600,14400,19200,38400,57600,115200,230400,460800,921600
  Serial1.println("$PMTK250,3,3,115200*1E");
  Serial1.println("$PMTK253,0*2A");
  Serial1.println(PMTK_SET_BAUD_115200);
  delay(500);
  Serial1.end();
  delay(500);
}

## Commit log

2020-01-22 Big update!
    Revamped the tests, showing the progression of the development.
    Updates to the PCB, including getting the clock and data pins in the right order.
    Moved some stuff to lib directory (Need to create issue to modularize these)
    Known bugs (Need to create issues for these):
    When hand moves into new pixel, the pixel sometimes flashes.
    Complete power cycle loses connection to GPS. Reset fixes.
    Hands reset early and sometimes jump around.
    [ABIMC Board.brd, ABIMC Board.sch]
2020-01-24 Updating tests to use all 6 strands now that I have the last two wired up
2020-01-27 Use 255 pixels instead of 256, fix fade in/fade out flash
    Fixes #2
    [main.cpp]
2020-01-27 Cycle colors through the spectrum once every 8 seconds
    Fixes #5
    [main.cpp]
2020-01-27 Don't overflow the unsigned longs
    Fixes #4
    Also fixes new issue where hand overlapping strand boundary would show up on other strand.
    Also fixes hour hand showing up where not configured (6th strand)
    [main.cpp]
2026-06-17 Clean up repo cruft and fix bring-up sketches
    - Drop EAGLE autosave/backup files (.b#, .s#), eagle.epf, and svg2poly.log
    from version control; keep the real .brd/.sch/.pro design files.
    - Stop tracking IDE files and ignore .idea/ and EAGLE backups going forward.
    - Fix the non-compiling adafruit_strand_test (duplicate STRAND_4_PIXELS
    defines and three strips all named strip4).
    - Remove a duplicated strand-4 advance block in fastled_strand_test.
    - Move standalone dev sketches out of test/ (reserved by PlatformIO for unit
    tests) into examples/ with a README describing each one.
    Claude-Session: https://claude.ai/code/ses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
    [main.cpp]
2026-06-17 Add dual licensing (MIT firmware + CERN-OHL-S hardware)
    Firmware (src/, lib/, examples/, test/) is MIT; the PCB and artwork are
    CERN-OHL-S v2. LICENSE.md explains the split.
    Claude-Session: https://claude.ai/code/session_01HAJ28v8jXB5RJFHovDxZVg
2026-06-17 Add CI, roadmap, and documentation
    - GitHub Actions workflow builds the firmware with PlatformIO on every push/PR.
    - ROADMAP.md captures the resurrection plan: hygiene, library extraction,
    deferred hardware v2 options, desk-sized enclosure, and magnet-based config.
    - Document the repository layout, build steps, and license in the README.
    - Fill in the empty abimc_pcb library README.
    - Set monitor_speed in platformio.ini to match the debug serial baud.
    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
2026-06-17 Fix CI: ignore incompatible bundled I2S library
    The first CI run failed compiling the Adafruit SAMD core's bundled I2S
    library, which references GCLK registers (STATUS/GENDIV/CLKCTRL) that no
    longer exist in the current Atmel CMSIS pack. FastLED's library dependency
    finder drags I2S in, but the APA102 strands use clocked SPI, so ignore it.
    Also restrict push-triggered CI to main so PR branches build once (via the
    pull_request event) instead of twice.
    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
2026-06-17 Fix build: call FastLED.addLeds on the instance, not statically
    Modern FastLED (3.10.x) makes addLeds a non-static member, so the old
    CFastLED::addLeds<...>() calls no longer compile. Call them on the global
    FastLED object like the example sketches already do.
    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
    [main.cpp]
2026-06-17 Fix build: drop unused Adafruit DotStar dependency
    The firmware drives the APA102 strands via FastLED and never includes
    Adafruit_DotStar. Keeping it as a dependency pulled in Adafruit BusIO, which
    needs Wire.h and broke the build. It is only used by the adafruit_strand_test
    example, which isn't part of the default build.
    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
2026-06-17 Fix ISR data races and out-of-bounds write in clock firmware
    The PPS interrupt shares state with the main loop, but nothing protected it:
    - Mark the interrupt-shared globals volatile so the compiler stops caching
    stale copies (currentMinute, ppsStartOf{Second,Minute}Millis, and the
    leap-second pair read inside the ISR).
    - Replace the broken torn-read guard in setClock() -- it compared
    ppsStartOfMinuteMillis to itself and re-read at most once -- with a
    noInterrupts() snapshot that copies currentMinute and ppsStartOfMinuteMillis
    as a consistent pair (the interrupt updates them together on rollover).
    - Wrap the seconds-hand write in updateStrandSeconds() with MOD so it can no
    longe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
    [main.cpp]
2026-06-17 Roadmap: apply the circular catch-up rule to seconds too
    The same speed-up-after-the-bottom correction that keeps the minute hands
    landing at the top of the hour also applies one level down to the seconds
    within a minute.
    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
2026-06-17 Snapshot millis() inside setClock()'s critical section
    Reading millis() after re-enabling interrupts left a small window where the
    PPS ISR could roll the minute over, making displayMillis post-rollover while
    displayStartOfMinuteMillis was pre-rollover and producing a >60s
    millisSinceStartOfMinute for a frame. Capture millis() under noInterrupts()
    with the rest of the snapshot so the time base stays consistent.
    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
2026-06-17 Roadmap: favor outsourced manufacturing over hand-assembly
    Record the maintainer's preference to farm fabrication out to services
    (turnkey PCBA, service-bureau enclosure prints) and minimize hand-soldering
    and hand-fitting, while staying inexpensive at hobby quantities. Weave the
    principle through the hardware tracks (module-over-dev-board, fab-placed LEDs,
    sockets/connectors over soldered wiring, print/CNC bureaus for the enclosure)
    and add a near-term task to export Gerbers/BOM/CPL so the current board is
    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
2026-06-17 Track B: extract hand geometry into host-tested abimc_render lib
    Begin breaking the monolithic firmware into pure, framework-agnostic libraries.
    - Add lib/abimc_render: a FastLED/Arduino-free library holding the hand
    positioning math (positive mod, and computeHand() which returns the lit
    pixels plus the sub-pixel leading/trailing fade and ring wrap-around). The
    mapping is identical to the original updateStrand() inline math.
    - Refactor src/main.cpp's updateStrand() to call computeHand() and only apply
    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

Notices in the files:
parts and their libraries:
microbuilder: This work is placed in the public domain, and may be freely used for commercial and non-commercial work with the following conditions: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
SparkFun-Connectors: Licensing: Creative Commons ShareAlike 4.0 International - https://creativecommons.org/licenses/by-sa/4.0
